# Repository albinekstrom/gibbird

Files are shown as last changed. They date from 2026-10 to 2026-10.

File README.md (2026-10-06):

# GibBird: balcony bird camera + e-ink frame

A camera on the balcony spots birds, works out the species, and an A4 colour
e-ink frame in the bedroom shows who visited today. It's based on teddymakesstuff's
"Avian Visitors" frame, but that one listens for birds (BirdNET audio, hence
"Heard Today") and this one watches with a camera.

It's set up for **Gothenburg** first: a curated list of 58 local species with Swedish
names and a Swedish poster. Everything that depends on location sits in one region
file, so you can make a list for anywhere else (see [Other locations](#other-locations)).

```
 BALCONY (outside the office window)            OFFICE (hidden behind the frame)
 ┌────────────────────────┐  2–3 m USB cable   ┌──────────────────────────────────┐
 │ IMX678 USB camera, 123°│ ─────────────────▶ │ Raspberry Pi 4                   │
 │ in a printed housing,  │                    │  gibbird cam:   motion → crop    │
 │ strapped to a railing  │                    │                 → classify       │
 │ post                   │                    │  gibbird frame: poster → driver  │
 └────────────────────────┘                    │  HAT → Waveshare 7.3" e-ink panel│
                                               └──────────────────────────────────┘
```

## Step-by-step

**Placement:** [docs/INSTALLATION.md](docs/INSTALLATION.md) describes where the frame,
camera, feeder and cables go (office window + balcony), plus the weatherproof camera
housing (`hardware/camera_housing.scad`).

1. **Buy the parts** (list below). Also get a feeder for the railing and place it
   about 1.2–1.5 m from the camera. The classifier needs the bird to fill a good part
   of the picture.
2. **Frame:** BGA "Ram Galant Glas" 13×18 cm. The 3D model's defaults match it. If you
   use another frame, measure its outer size, the recess (`rabbet`) and its depth.
3. **Print** `back`, `panel_tray`, `pod_cover` and `stand` from `hardware/frame_back.scad`,
   and `body`, `lid` and `bracket` from `hardware/camera_housing.scad`
   (see [3D print](#3d-printed-back)).
4. **Flash the SD card** with Raspberry Pi Imager → *Raspberry Pi OS Lite (64-bit)*.
   In the Imager settings, set Wi-Fi, enable SSH, and use the hostname `birdframe`.
5. **Build the frame.** Glass → passepartout → display panel → printed panel tray, in
   that order, into the frame. Feed the panel's flat cable through the tray's slot.
   Take the Pi 4 out of its aluminium case (keep the stick-on heatsinks), screw it onto
   the four bosses in the printed back, and plug the driver HAT onto it. Then connect
   the flat cable to the HAT and screw the back onto the frame. Power and camera cables
   leave through the spine at the bottom edge.
6. **Mount the camera** on a railing post next to the office window, with two hose
   clamps (see [docs/INSTALLATION.md](docs/INSTALLATION.md)). Run the cable along the
   window frame, in through the window seal, and up the spine.
7. **Install the software** ([Software](#software)). Use `gibbird classify` on a few
   photos and check the web page at `http://birdframe.local:8080`.
8. **Calibrate** at `http://birdframe.local:8080/calibrate` ([below](#zones-and-calibration)).
9. **Tune** `min_score`, the camera angle and the feeder position in the first week.

## Shopping list

This is the current build: a Pi 4 behind a Waveshare 7.3" e-ink panel, and an IMX678
USB camera outside the office window. Prices are from amazon.se, October 2026.

**Already owned:** Raspberry Pi 4 Model B with its fan and heatsinks, the official Pi 4
USB-C power supply, a microSD 32 GB High Endurance card, and the BGA "Ram Galant Glas"
13×18 cm frame (walnut).

**Main parts**

| Part | Notes | ≈ Price |
|---|---|---|
| **Waveshare 7.3" 6‑Color e‑Paper HAT (E)** (E Ink Spectra 6, 800×480) | Comes with the driver board and a 40-pin extension header. The driver board plugs straight onto the Pi, so no ribbon cable is needed | 1 258 kr |
| **Iyalezirk IMX678 USB camera module, 8 MP, 123°** | USB, 4K MJPEG, 38×38 mm board. Sony Starvis 2 sensor, good in grey winter light. Sold by a third-party seller | 864 kr + 33 kr |

**For the frame and the Pi**

| Part | Notes | ≈ Price |
|---|---|---|
| 90° USB-C adapter (male → female), **sideways-bent** type (plug comes out of the adapter's side) | The cable then turns down along the board towards the spine. Flip it 180° if it points up | 50–100 kr |
| USB-A → 2-pin fan cable, 5 V | Powers the Pi-Fan from a USB port, since the display board takes the GPIO pins | 30–60 kr |
| Screw kit M2.5 + M3 (stainless) | Pi 4× M2.5×6, pod cover 4× M3×10 countersunk, stand 2× M3×16 | 100–200 kr |
| 6× wood screws 2.5×10 mm countersunk | Back plate to the frame (pre-drill 1.5 mm) | 30–50 kr |
| Self-adhesive soft foam sheet (EVA), 3 mm | One layer in the panel tray's pocket supports the glass panel evenly (`foam_t` = 2.5 mm compressed) | 50–100 kr |
| PLA or PETG filament, ~300 g | For the indoor frame back and panel tray | – |
| Passepartout, white or black, 13×18 cm outer, window about **95×159 mm** | Hides the panel's border; window just inside the image area (160×96 mm). BGA's made-to-measure mat (179,90 kr), or cut black card yourself. Measure the panel first | 0–180 kr |

**For the camera outside**

| Part | Notes | ≈ Price |
|---|---|---|
| USB 2.0 extension, A‑male → A‑female, 2–3 m, **carries data** (flat if it crosses the window seal) | From the camera's cable to the Pi | 80–150 kr |
| 2× stainless hose clamps (band ≤ 12 mm) | Strap the camera bracket to a railing post without drilling. Choose a size that fits around the post plus the 8 mm base | 40–80 kr |
| EPDM/rubber tape | Between the bracket and the railing, to grip and protect the paint | 50 kr |
| Cable gland, IP68 (PG7 for a 3–6 mm cable, PG9 for 4–8 mm) | Seals the cable into the housing. Feed the camera end of the cable through it, since a USB-A plug won't fit. Set `gland_d` to the gland's thread | 50–80 kr |
| 2 mm plexiglas (acrylic) sheet, small piece | Score with a knife and snap a **32×32 mm** square for the housing's window (Bauhaus, Biltema, Jula) | 50–100 kr |
| 2 mm silicone O-ring cord or EPDM foam gasket tape | Seals the housing lid | 50–100 kr |
| Clear outdoor silicone | Glues the window disc in | 60–100 kr |
| Silica gel sachets | Keep the housing dry; replace each autumn | 40–80 kr |
| ASA filament (PETG works; never PLA outdoors) | For the camera housing and bracket | 250–350 kr |
| Feeder for the railing + sunflower seeds | 1.2–1.5 m from the camera. Check your housing association's rules first | 150–350 kr |
| Optional: conformal coating spray | Extra moisture protection for the camera board | 100 kr |

**Total for what's left to buy:** about **3 000–3 500 kr** including the display and camera.

## 3D-printed back

`hardware/frame_back.scad` is parametric. Install [OpenSCAD](https://openscad.org)
(the `openscad@snapshot` Homebrew cask works on macOS), open the file and use the
Customizer panel.

| Stand open | Stand closed |
|---|---|
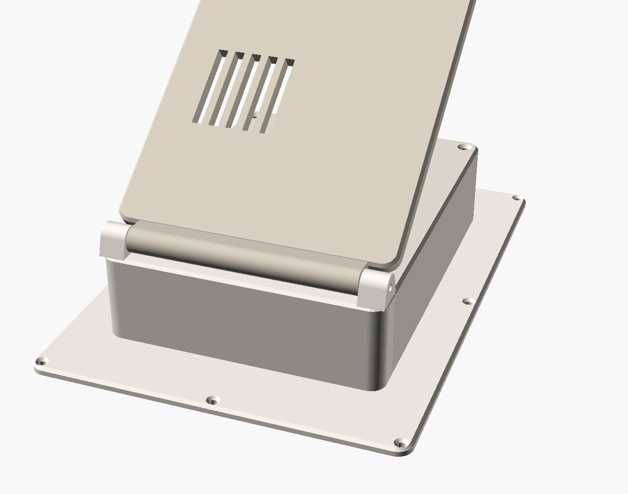
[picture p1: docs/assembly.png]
Back with the stand open
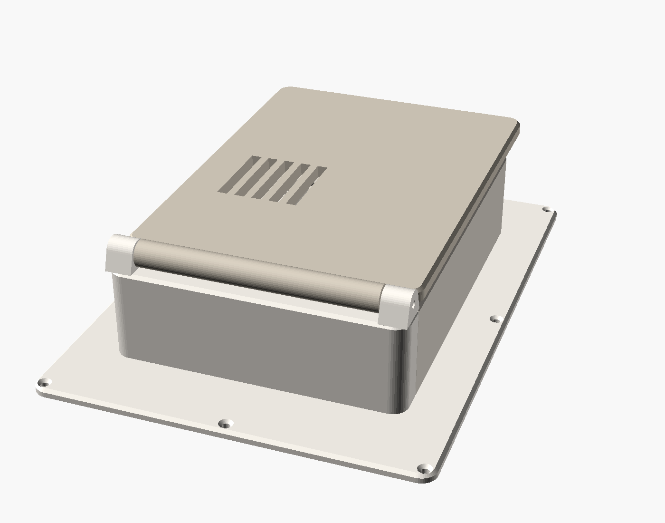
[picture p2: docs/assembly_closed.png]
Back with the stand closed
|  |  |

The back is one clean central column, and nothing else is visible:

- **Inside the frame:** glass → passepartout → **display panel** → **panel tray**. The
  tray is printed and holds the thin glass panel centred, supports its whole back
  (put a thin layer of foam in its pocket), and fills the rest of the 9 mm recess, so
  the back plate presses on it when screwed on.
- **Pod.** Hides the Pi (4 or 5) with the Waveshare driver HAT. The Pi screws onto four
  bosses on the plate. The pod **cover** is a separate part, printed roof-down for a
  smooth finish with no sagging spans. It comes off with 4 screws that are hidden
  under the stand, so you can reach the Pi without taking the back off the frame.
- **Fan.** A 30 mm fan mount and grille in the cover's roof, placed clear of the
  driver HAT. Air comes in through slots in the cover's bottom wall.
- **Spine.** A hollow channel from the pod down to the bottom edge, sloping down so the
  frame can lean back on its stand without the pod touching the table. The panel's
  flat cable comes up through a slot into the spine and runs inside it to the HAT. The
  power and camera cables leave through the spine at the bottom edge. Use a **90° USB‑C
  adapter**: there are 20 mm beside the Pi for the plug.
- **Stand.** A solid flap that closes over the pod and spine, so from behind the frame
  looks like a slab with one neat block on it. It has vent slots over the fan. It
  pivots on two M3×16 screws in towers at the top of the pod, and a stop tab sets the
  angle (`stand_open`, default 35°).
- **Plate.** 147×197 mm with rounded corners and softened edges, printed in one piece.
  It screws onto the frame with 6 small countersunk screws (2.5×10, pre-drill 1.5 mm).
  For a bigger frame, set `split_y` and print it in two glued halves.

**Assembly:** panel and tray into the frame (flat cable through the tray's slot) →
screw the Pi onto the bosses → plug the driver HAT onto the Pi (with its extension
header) → thread the power and camera cables up through the spine and plug them in
→ connect the panel's flat cable to the HAT → screw the back onto the frame → screw
the fan into the cover and plug its USB lead into the Pi → screw on the cover
(4× M3×10) → fit the stand (2× M3×16).

**Check when the display arrives:** the panel's outline (`panel`, default 111.2×170.2 mm),
its thickness, which edge the flat cable leaves from (`fpc_edge`, default bottom), and
the cable's width and length. If the cable is too short to reach the driver HAT, a
24-pin 0.5 mm FPC extension solves it. The file refuses to render if the cable slot
doesn't open into the spine or pod, if the slot is under the Pi, if the panel doesn't
fit the frame, or if the fan would sit over the HAT. The `stl/` folder has exports
made with the default numbers.

No part needs supports: plate and panel tray flat side down, cover roof down, stand
pod-side down. Use 0.2 mm layers, 3 walls and 15 % infill. PETG handles a warm windowsill
better than PLA. A matte or silk filament in one colour gives the cleanest look.

## Software

```
gibbird/           Python package
  camera.py        Picamera2 / OpenCV frame sources
  motion.py        background-subtraction motion detector + crop
  classifier.py    TFLite / LiteRT classifier (Google iNat birds, 964 species)
  watcher.py       motion → classify → confirm over several frames → visits
  store.py         SQLite visit log
  server.py        HTTP API + a simple phone page
  calibration.py   detection zones, image → real-world (cm) homography, size filter
  web/             calibration page
  render.py        e-ink poster (1200×1600) + language strings
  frame_app.py     polling, change detection, quiet hours
  data/regions/    species lists (gothenburg.csv)
hardware/          OpenSCAD model + STLs
scripts/           model download, region generator
systemd/           services (camera + frame, both on the same Pi)
```

How detection works. A low-resolution stream is checked for motion. Each moving region
is cut out of the full-resolution frame (12 MP on Camera Module 3) as a square, padded, and classified. A
species only counts when it wins 2 of 4 checks in a row, and it must be on the region
list. This stops the model from reporting, say, an American goldfinch in Gothenburg.
Sightings less than 2 minutes apart count as one visit. The most confident photo of
each visit is kept.

### Zones and calibration

Open `http://birdframe.local:8080/calibrate` while `gibbird cam` is running. It shows
a live snapshot.

- **Zones.** Outline where birds should be detected: railing, feeder, flower box.
  Motion outside the zones is ignored, so trees, the street and neighbours don't
  trigger anything.
- **Reference points.** Choose one flat surface where birds land, for example the
  face of the railing. Click 4 or more spots on it that you've measured with a tape,
  and type their positions in cm. From these the Pi works out how the picture maps to
  real centimetres. A white 50 cm grid is then drawn over the snapshot so you can
  check the fit. With 5 or more points it also shows a fit error.
- **What calibration gives you.** Zones are stored in centimetres. If the camera gets
  bumped, redo only the reference points and the zones stay where they were in the
  real world. Moving things outside the bird size range (default 6–80 cm) are ignored,
  such as a cat, a person or a flapping towel. Sizes are measured on the reference
  surface, so things far in front of or behind it are measured less accurately.

Everything is saved to `data/calibration.json` and applied immediately, without a
restart. The page has no login, so only use it on your home network.

The frame redraws only when the set of species or visit counts changes. It waits at
least 15 minutes between refreshes and stays dark 23:00–07:00. A full Spectra
refresh takes about 30 s and flashes. If nothing has been seen today, it shows the
last 7 days instead.

### Raspberry Pi (`birdframe`): deploy from your computer

You develop on your Mac and push to the Pi over SSH. The Pi doesn't need git or GitHub.

```bash
cp config.example.toml config.toml        # edit locally; it is copied on every deploy
scripts/deploy.sh --setup                  # first time: packages, SPI/I2C, venv, services
                                           # (reboots once; then run scripts/deploy.sh again)
scripts/deploy.sh                          # after every change: sync + restart
scripts/deploy.sh --logs                   # follow the logs
scripts/deploy.sh --status                 # services + CPU temperature
```

The target defaults to `albin@birdframe.local`; set `GIBBIRD_HOST=user@host` to change
it. The deploy uses rsync and leaves the Pi's `data/` folder (visits, photos,
calibration) and its Python environment alone. Python packages are only reinstalled
when `pyproject.toml` changes.

If the poster comes out upside down, set `rotation = 270`.

### On your Mac (no hardware)

```bash
python3 -m venv .venv && .venv/bin/pip install -e '.[dev]' ai-edge-litert
scripts/download_model.sh
.venv/bin/pytest
.venv/bin/gibbird -c config.example.toml classify photo.jpg      # test the model
.venv/bin/gibbird -c config.example.toml demo --photos ~/birds   # poster.png, dithered like the panel
.venv/bin/gibbird -c config.example.toml frame --once --preview p.png  # against a running cam
```

To run the full camera pipeline on a laptop, set `source = "opencv:0"` (webcam) or
`source = "clip.mp4"` (a video file).

## Other locations

```bash
# Uses GBIF bird records within 15 km. Local names in any ISO 639-2 language (swe, deu, fra, …)
python3 scripts/make_region.py --lat 59.33 --lon 18.07 --radius 15 --lang swe \
    --min-records 200 --out gibbird/data/regions/stockholm.csv
```

Then set `region = "stockholm"` in `config.toml`. The generated list includes ducks,
waders and seabirds that won't land on a balcony. Delete those rows by hand, as was
done for `gothenburg.csv`. You can also add `aliases` for look-alikes the model knows
under another name (e.g. *Corvus corone* → Hooded Crow).
For poster text in another language, add an entry to `TEXT` in `gibbird/render.py`.

## Ideas for later

- Raspberry Pi AI Camera or AI HAT+ for a real bird detector instead of motion.
- Add BirdNET (audio) as well, like the original, so it covers "heard" and "seen".
- A weekly poster on Sundays, and a "first of the year" highlight.

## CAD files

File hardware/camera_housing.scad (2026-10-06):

// GibBird — weatherproof housing v2 for a small USB board camera (default: the 38 x 38 mm
// IMX678 8MP 123° USB module), plus a tilting bracket that straps onto a balcony railing post.
//
// Use orientation: the camera looks along +Z, +Y is up. A smooth rounded shell with a
// rain hood over the window, sized from the lens's field of view so it never shows in
// the picture; the lid closes the back flush, with a gasket in
// a groove and a PG9 cable gland (big enough to pass a USB-A plug). All screws are
// inside the shell or under the lid. The board is held by four ribs and pressed into
// place by pegs on the lid, so it needs no screws.
//
// Built for Swedish weather (rain, snow, frost): print in ASA (best: UV- and cold-proof) or PETG,
// never PLA (brittle in frost, soft in sun). 4 walls, 30 % infill, no supports:
//   body:    back opening on the bed
//   lid:     outer face on the bed
//   bracket: base on the bed
//
// Mounting on the balcony railing (no drilling): two stainless hose clamps run through the
// tunnels in the bracket base and around a railing post; a groove in the back of the base
// centres it on the post. Put a strip of EPDM/rubber tape between bracket and post. The
// base also has two countersunk holes for screws or outdoor VHB tape on a flat surface.
//
// Hardware: 4x M3 x 12 + washers (lid), 2x M4 x 10 + washers (tilt, self-tapping),
// 2x stainless hose clamps (band <= 12 mm, size to fit post + base), PG9 cable gland,
// 2 mm acrylic window pane (32 x 32 mm square, cut from a sheet) + clear silicone, 2 mm silicone O-ring
// cord (or 2 mm foam gasket tape), a silica gel sachet.

part = "assembly"; // [assembly, body, lid, bracket]

/* [Camera board: MEASURE YOURS] */
board = [38, 38];
board_t = 1.6;
lens_len = 22;        // board front face -> front of the lens
lens_d = 12;          // diameter of the lens's front
fov_d = 123;          // diagonal field of view (IMX678 module: 123°)
aspect = [16, 9];
behind = 18;          // room behind the board for the connector and the gland

/* [Window] */
pane = "square";      // "square": a 2 mm acrylic piece you score and snap yourself (easy to make);
                      // "round": a bought round disc of disc_d
pane_size = 32;       // side of the square pane
disc_t = 2;           // pane thickness
hood_max = 20;        // rain/snow hood beyond the window; shortened automatically so the
                      // lens never sees it

/* [Shell] */
wall = 3.0;           // thick walls keep the camera's own heat in during winter
clear = 7;            // space around the board on each side (room for the screw bosses)
front_t = 3;
radius = 8;           // vertical edges
chamfer = 1.5;
boss = 7;             // lid screw bosses in the inside corners
screw_pilot = 2.6;    // M3 self-taps into the bosses
screw_clear = 3.4;
lid_t = 4;
groove_w = 1.8;       // gasket groove in the lid for 2 mm cord
groove_depth = 1.4;

/* [Cable] */
gland_d = 15.6;       // hole for the cable gland's thread: PG9 15.6, PG7 12.9, M12 12.4,
                      // M16 16.4. Feed the camera end of the cable through the gland.
weep_d = 2;

/* [Mount] */
pivot_boss_t = 5;     // round pads on the sides for the tilt screws
pivot_pilot = 3.4;    // M4 self-taps into the pads
pivot_clear = 4.4;
arm_t = 5;
arm_w = 16;
base = [76, 40, 8];   // thick enough for the hose-clamp tunnels
base_screw = 4.5;
post_w = 40;          // width of the railing post the bracket straps to (MEASURE)
strap = [13, 2.6];    // hose-clamp band tunnel (width, height)

/* [Hidden] */
$fn = 64;
eps = 0.01;
in_w = board.x + 2 * clear;
in_h = board.y + 2 * clear;
W = in_w + 2 * wall;
H = in_h + 2 * wall;
standoff = lens_len + 1;                   // lens stops 1 mm behind the window
// Field of view -> window size and the longest hood that stays out of the picture.
tan_d = tan(fov_d / 2);
tan_v = tan_d * aspect.y / norm(aspect);
win_d = ceil(lens_d + 2 * (front_t + 1) * tan_d + 1);
disc_d = win_d + 4;   // round pane diameter (when pane = "round")
hood_len = min(hood_max, floor((board.y / 2 + clear - win_d / 2) / tan_v) - 1);
D_in = standoff + board_t + behind;
D = D_in + front_t;
board_z = D_in - standoff - board_t;       // board's back face
corners = [for (sx = [-1, 1], sy = [-1, 1]) [sx, sy]];
boss_xy = [in_w / 2 - boss / 2, in_h / 2 - boss / 2];
pivot_z = D / 2;
arm_gap = W + 2 * pivot_boss_t + 1;
pivot_h = sqrt(pow(H / 2, 2) + pow(D / 2 + hood_len, 2)) + 3;   // room to tilt

echo(str("housing ", W, " x ", H, " x ", D + hood_len, " mm; window ", win_d, " mm, disc ", disc_d,
         " mm; hood ", hood_len, " mm; board back at z = ", board_z));
assert(disc_d / 2 < board.x / 2 - 2, "window disc too big to pass the board ribs: use a smaller lens_d/fov");
assert(pane != "square" || (pane_size / 2 < board.x / 2 - 2 && pane_size >= win_d + 3),
       "square pane must cover the window (win_d + 3) and pass the board ribs");

module rsquare(size, r) { offset(r = r) offset(delta = -r) square(size, center = true); }

module shell_solid(h) {
    hull() {
        linear_extrude(h - chamfer) rsquare([W, H], radius);
        translate([0, 0, h - chamfer]) linear_extrude(chamfer) rsquare([W - 2 * chamfer, H - 2 * chamfer], radius - chamfer);
    }
}

module body() {
    difference() {
        union() {
            shell_solid(D);
            // rain/snow hood: the roof continues past the window. Only the roof: with a
            // wide lens, side cheeks would show in the picture.
            translate([0, 0, D - eps]) difference() {
                intersection() {
                    linear_extrude(hood_len) rsquare([W, H], radius);
                    translate([-W, H / 2 - wall, 0]) cube([2 * W, wall, hood_len]);
                }
                // drip groove under the front edge, so water falls off instead of creeping back
                translate([-W, H / 2 - wall - 1, hood_len - 4]) cube([2 * W, 1.6, 1.6]);
            }
            // round pads for the tilt screws
            for (s = [-1, 1])
                translate([s * (W / 2 + pivot_boss_t / 2 - 1), 0, pivot_z])
                    rotate([0, 90, 0]) cylinder(d = arm_w, h = pivot_boss_t + 2, center = true);
        }
        // cavity
        translate([0, 0, -1]) linear_extrude(D_in + 1) rsquare([in_w, in_h], 2);
        // window, and the disc's seat on the inside of the front wall
        translate([0, 0, D_in - 1]) cylinder(d = win_d, h = front_t + 2);
        if (pane == "square")
            translate([-(pane_size + 0.4) / 2, -(pane_size + 0.4) / 2, D_in - eps]) cube([pane_size + 0.4, pane_size + 0.4, disc_t]);
        else
            translate([0, 0, D_in - eps]) cylinder(d = disc_d + 0.4, h = disc_t);
        // weep hole at the front of the bottom wall
        translate([0, -H / 2 - 1, D_in - 4]) rotate([-90, 0, 0]) cylinder(d = weep_d, h = wall + 2);
        // blind pilot holes in the pads (they stop short of the cavity)
        for (s = [-1, 1])
            translate([s * (W / 2 + pivot_boss_t + 1), 0, pivot_z])
                rotate([0, s > 0 ? -90 : 90, 0]) cylinder(d = pivot_pilot, h = pivot_boss_t + 2.5);
    }
    // inside: lid screw bosses in the corners...
    difference() {
        for (c = corners) translate([c.x * boss_xy.x, c.y * boss_xy.y, 0]) linear_extrude(D_in) square(boss, center = true);
        for (c = corners) translate([c.x * boss_xy.x, c.y * boss_xy.y, -1]) cylinder(d = screw_pilot, h = 13);
    }
    // ...and a rib on each wall that the board rests against (chamfered: prints without support)
    rib_reach = in_w / 2 - board.x / 2 + 2;
    for (a = [0, 90, 180, 270]) rotate([0, 0, a])
        hull() {
            translate([in_w / 2 - rib_reach, -4, board_z + board_t]) cube([rib_reach, 8, D_in - board_z - board_t]);
            translate([in_w / 2 - eps, -4, board_z + board_t - rib_reach]) cube([eps, 8, eps]);
        }
}
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

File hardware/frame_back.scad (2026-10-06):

// GibBird — back cover v2 for a picture frame holding a Waveshare 7.3" e-Paper (E) panel,
// with a Raspberry Pi 4/5 (+ the Waveshare driver HAT) hidden behind it.
//
// Coordinates are seen FROM THE BACK with the frame standing in portrait.
// Origin = bottom-left corner of the frame's back face, Z points away from the display.
//
// Design: one clean central column. A pod hides the Pi (its cover comes off with 4
// screws hidden under the stand), a hollow spine carries the power and camera cables
// out to the bottom edge, and a solid flip-out stand closes over both, so from behind
// the frame looks like a slab with a single neat block on it.
//
// Inside the frame, front to back: glass, passepartout (mat), display panel, and a printed
// tray that holds the thin glass panel centred and supports its whole back. The tray fills
// the rest of the frame's recess, so the back plate presses on it when screwed on.
//
// Parts and print orientation (all without supports):
//   back                    flat side down (frames up to ~250 mm fit in one piece;
//                           bigger ones: set split_y and print back_lower + back_upper)
//   panel_tray              flat side down
//   pod_cover               roof down (a textured plate gives a nice finish)
//   stand                   pod side down
//
// Workflow: measure your frame + display, edit the [Frame] and [Display header] values,
// pick a `part`, press F6 (render), then File > Export > STL.

part = "assembly"; // [assembly, back, back_lower, back_upper, panel_tray, pod_cover, stand]

/* [Frame: MEASURE YOURS] */
// Defaults: BGA "Ram Galant Glas" 13x18 cm (14.7 x 19.7 cm outside, 13 mm profile, 9 mm recess).
frame_w = 147;        // outer width of the frame (portrait)
frame_h = 197;        // outer height
rabbet_w = 131;       // recess on the back where the picture goes (13x18 cm + play)
rabbet_h = 181;
rabbet_depth = 9;     // "falsdjup"
glass_t = 2;
mat_t = 1.4;          // passepartout; 0 if you don't use one

/* [Display panel: Waveshare 7.3" e-Paper (E), portrait. CHECK when it arrives] */
panel = [111.2, 170.2];  // outline of the glass panel
panel_t = 1.2;
foam_t = 2.5;            // foam behind the panel, compressed (3 mm self-adhesive EVA sheet)
panel_shift = [0, 0];    // move the panel off-centre in the recess (mm)
fpc_edge = "bottom";     // edge where the flat cable leaves the panel: bottom|top|left|right
fpc_w = 26;              // width of the flat cable
fpc_pos = 0;             // cable position along that edge, from its centre (mm)

/* [Pod: hides the Raspberry Pi] */
pod_w = 110;
pod_y0 = 26;          // bottom edge of the pod, frame coordinates. High enough that the pod
                      // doesn't touch the table when the frame leans back on its stand.
cable_room = 20;      // inside the pod, right of and below the Pi, for cables
plug_room = 20;       // above the USB-A ports, for a right-angle plug
boss_h = 4;           // Pi stands this far above the plate (M2.5 x 6 screws)
boss_d = 6;
boss_hole_d = 2.2;
pi_tall = 24;         // tallest part above the Pi's board (driver HAT on its extension header)
hat = [65, 30];       // driver HAT footprint, lying along the Pi's GPIO edge
wall = 2.4;
roof_t = 2.4;
radius = 6;           // corner radius of plate, pod and stand
chamfer = 1.2;        // softened top edges
cover_screw = 3.4;    // 4x M3 x 10 countersunk, into bosses on the plate
cover_pilot = 2.6;

/* [Fan: 30 mm 5 V fan over the SoC, exhausting through the roof] */
fan = true;
fan_size = 30;
fan_t = 7;
fan_hole_spacing = 24;
fan_screw_d = 3.2;
fan_at = [45, 10];    // in Pi board coordinates; kept clear of the driver HAT, which covers
                      // the SoC side of the board, and blowing down past it

/* [Spine: hollow channel for the cables (and the panel's flat cable)] */
spine_w = 40;
spine_low = 12;       // height at the bottom edge; slopes up to the pod so the frame can lean back

/* [Back plate] */
plate_t = 3.2;
screw_d = 2.9;        // 6x wood screws 2.5 x 10 mm into the frame (pre-drill 1.5 mm)
screw_head_d = 5.2;

/* [Stand] */
stand_open = 35;      // how far the stand swings open (deg)
flap_t = 5;
hinge_r = 5;
hinge_gap = 0.6;
knuckle_w = 10;       // hinge towers at both ends
knuckle_clear = 0.5;
pin_d = 3.3;          // stand pivots on the smooth shank of an M3 x 16 screw...
pin_tap_d = 2.8;      // ...which self-taps into the hinge tower
pin_depth = 12;

/* [Split for printers smaller than the frame] */
split_y = 0;          // 0 = print the plate in one piece
lap = 16;

/* [Hidden] */
$fn = 48;
eps = 0.01;
pi_board = [56, 85];  // Pi lying vertically: GPIO edge left, USB-C right, USB-A at top
m_x = (frame_w - rabbet_w) / 2;
m_y = (frame_h - rabbet_h) / 2;
tray_t = rabbet_depth - glass_t - mat_t - 0.3;   // tray fills the recess behind the panel
panel0 = [m_x + (rabbet_w - panel.x) / 2, m_y + (rabbet_h - panel.y) / 2] + panel_shift;
panel1 = panel0 + panel;
// Slot for the panel's flat cable, just inside the edge it leaves from.
slot_l = fpc_w + 6;
slot_d = 8;
hdr = fpc_edge == "bottom" ? [(panel0.x + panel1.x) / 2 + fpc_pos, panel0.y + slot_d / 2 + 1]
    : fpc_edge == "top"    ? [(panel0.x + panel1.x) / 2 + fpc_pos, panel1.y - slot_d / 2 - 1]
    : fpc_edge == "left"   ? [panel0.x + slot_d / 2 + 1, (panel0.y + panel1.y) / 2 + fpc_pos]
    :                        [panel1.x - slot_d / 2 - 1, (panel0.y + panel1.y) / 2 + fpc_pos];
hdr_open = fpc_edge == "bottom" || fpc_edge == "top" ? [slot_l, slot_d] : [slot_d, slot_l];
pod_cx = frame_w / 2;
pod_x0 = pod_cx - pod_w / 2;
pod_x1 = pod_cx + pod_w / 2;
pod_in_x0 = pod_x0 + wall;
pod_in_x1 = pod_x1 - wall;
pod_in_y0 = pod_y0 + wall;
board0 = [pod_in_x1 - cable_room - pi_board.x, pod_in_y0 + cable_room];
pod_in_y1 = board0.y + pi_board.y + plug_room;
pod_y1 = pod_in_y1 + wall;
pod_in_h = boss_h + 1.6 + pi_tall + 3;        // above the plate top
top_z = plate_t + pod_in_h + roof_t;          // top of pod, spine and hinge base
axis_y = pod_y1 + hinge_r + 1.5;
axis_z = top_z + hinge_gap + hinge_r;
hinge_y1 = axis_y + hinge_r + 2;              // top edge of the hinge base
flap_len = axis_y - 3;
// Stop tab behind the hinge: it touches the hinge base exactly at `stand_open`.
tail = (hinge_r + hinge_gap - hinge_r * cos(stand_open)) / sin(stand_open);
function on_plate(p) = [board0.x + pi_board.x - p.y, board0.y + p.x];
pi_holes = [for (x = [3.5, 61.5], y = [3.5, 52.5]) on_plate([x, y])];
fan_c = on_plate(fan_at);
cover_bosses = [for (x = [pod_in_x0 + 3.5, pod_in_x1 - 3.5], y = [pod_in_y0 + 3.5, pod_in_y1 - 3.5]) [x, y]];
hdr0 = hdr - hdr_open / 2;
hdr1 = hdr + hdr_open / 2;

in_spine = hdr0.x >= pod_cx - spine_w / 2 + wall && hdr1.x <= pod_cx + spine_w / 2 - wall && hdr1.y <= pod_y0;
in_pod = hdr0.x >= pod_in_x0 && hdr1.x <= pod_in_x1 && hdr0.y >= pod_in_y0 && hdr1.y <= pod_in_y1;
assert(in_spine || in_pod, "the panel's cable slot must open into the spine or the pod: check fpc_edge/pod_y0");
assert(hdr1.x + 2 < board0.x || hdr0.x - 2 > board0.x + pi_board.x || hdr1.y + 2 < board0.y
       || hdr0.y - 2 > board0.y + pi_board.y, "the cable slot is under the Pi: raise cable_room");
assert(tray_t > panel_t + foam_t + 1.2, "the frame's recess is too shallow for glass + mat + panel + foam + tray");
assert(panel.x < rabbet_w && panel.y < rabbet_h, "the panel doesn't fit in the frame's recess");
// The fan must not sit over the driver HAT (HAT: GPIO edge = board y 56, inwards by hat.y).
assert(!fan || fan_at.y + fan_size / 2 < pi_board.x - hat.y, "fan is over the driver HAT: move fan_at");
for (b = cover_bosses)
    assert(b.x + 3.5 < hdr0.x || b.x - 3.5 > hdr1.x || b.y + 3.5 < hdr0.y || b.y - 3.5 > hdr1.y,
           "a cover screw boss is over the display header opening");
assert(split_y == 0 || split_y + lap / 2 < pod_y0, "the split seam runs through the pod: lower split_y");
assert(hinge_y1 < frame_h - 5, "the stand hinge is above the top of the frame");
assert(!fan || pod_in_h - boss_h - 1.6 - fan_t >= 8, "no room for the fan above the Pi's heatsinks");

echo(str("pod ", pod_w, " x ", pod_y1 - pod_y0, " mm, ", top_z, " mm deep; stand ", pod_w, " x ",
         flap_len, " mm; stop tab ", tail, " mm"));

// ---- helpers ---------------------------------------------------------------

module rbox2d(p0, p1, r) { translate(p0) offset(r = r) offset(delta = -r) square(p1 - p0); }

// Rectangle with selectively rounded corners: round = [bottom-left, bottom-right, top-right, top-left].
module rbox2d_sel(p0, p1, r, round) {
    pts = [[p0.x, p0.y], [p1.x, p0.y], [p1.x, p1.y], [p0.x, p1.y]];
    dirs = [[1, 1], [-1, 1], [-1, -1], [1, -1]];
    hull() for (i = [0 : 3])
        if (round[i]) translate(pts[i] + dirs[i] * r) circle(r = r);
        else translate(pts[i] + (dirs[i] - [1, 1]) * 0.005) square(0.01);
}
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

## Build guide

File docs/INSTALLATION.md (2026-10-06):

# Where everything goes

The frame stands in the office window, and the camera sits just outside that window,
looking at the balcony next to it. The camera cable comes in through the window
seal, so you don't drill anything and the cable run is short.

| Camera housing, front | Back (lid with gasket and cable gland) |
|---|---|
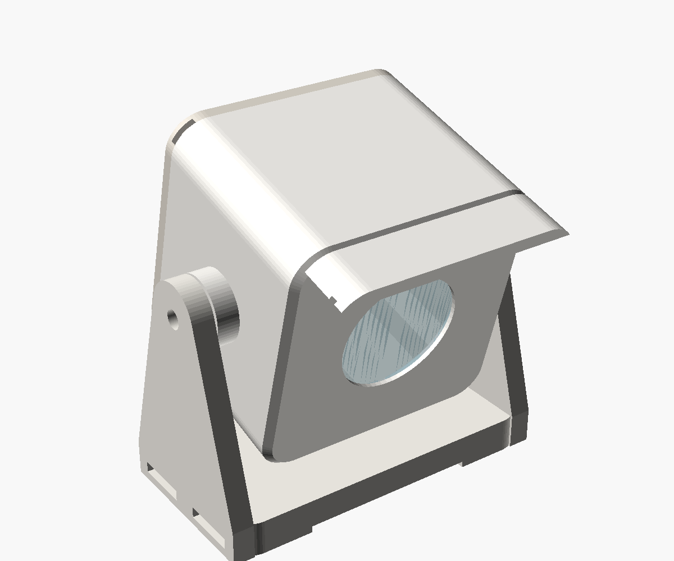
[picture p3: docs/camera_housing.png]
Camera housing, front
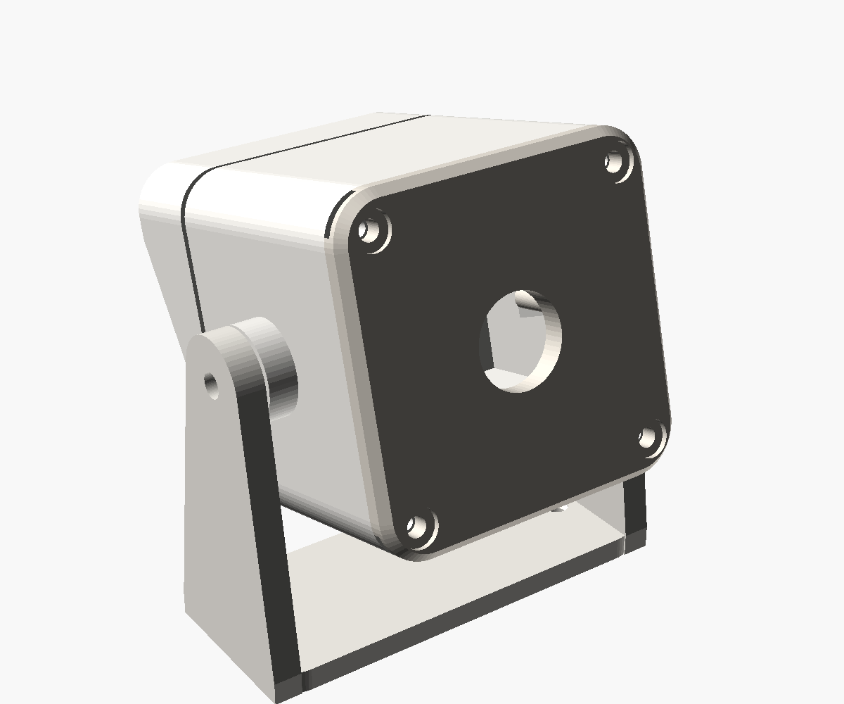
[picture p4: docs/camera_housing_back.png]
Camera housing, back
|  |  |

## Overview (seen from above)

```
                         ┌─────────────────────────── balcony railing ─────┐
                         │  ▲ flower boxes on the far railing              │
                         │                                                 │
                         │        BALCONY                                  │
                         │                                 ◆ FEEDER        │
                         │                                 (on the railing │
                         │                                  nearest the    │
                         │                                  window,        │
                         │                                  1–2 m from cam)│
   facade ───────────────┴──────────┐   ╲  view                           ─┘
                                     │    ╲
                           CAMERA ●──┘     (10–20° down, away from the sky)
       (outside, on the fixed window frame,
        upper left corner, under the slab above)
                                     ┊ cable: drip loop, then along the frame
   ══════════════ OFFICE WINDOW ═════╪══════════════════════════  (opens inwards)
                                     ┊ flat USB cable through the hinge-side seal
   ┌───────────── window seat / wooden shelf ─────────────────────┐
   │   [ FRAME ]  ← Pi 4 hidden in the back,      wall socket →  ◘ │
   │    stands on its flip-out stand                               │
   └───────────────────────────────────────────────────────────────┘
```

## 1. Camera: outside the window, upper left corner

**Where:** on the *fixed* outer window frame (the part that doesn't open), at the
upper left corner on the balcony side. Put it about 20–40 cm below the balcony slab
above, which keeps most of the rain off.

**Aim:** sideways along the facade, at the side of the balcony railing nearest the
window. Tilt it 10–20° down. That keeps the sky out of the picture (bright sky makes
the birds come out dark) and lets water run off the window disc. Your second photo is
roughly this view.

**Distance:** the feeder or perch should be **1–2 m** from the camera. With a wide 4K
camera, a 12 cm bird is about 190 px across at 1 m and 95 px at 2 m. The classifier
needs about 100 px to be reliable.

**Mounting on the balcony railing (recommended, no drilling):** strap the bracket to a
railing post with **two stainless hose clamps**. They run through the tunnels in the
bracket base, and a groove in the back of the base centres it on the post (set
`post_w` in the model to your post's width). Put a strip of rubber tape underneath so
it grips and doesn't scratch the paint. Tighten the clamps, set the tilt and pan by
eye using the live view at `/calibrate`, then tighten the two tilt screws.

**Other mounting options** (the base of the tilt bracket):
- **Without drilling:** outdoor double-sided tape (3M VHB, outdoor grade). Clean and
  dry the paint first, and apply it above 10 °C so it bonds. Let it set for 24 hours
  before you hang the camera on it. This is reversible, which is good if the
  housing association or landlord has rules about the facade.
- **With screws:** 2 stainless screws, 4×25 mm, into the wooden window frame. Ask the
  housing association (BRF) or landlord first.
- **Never on the opening sash.** It moves, and the camera would lose its aim.

## 2. Feeder

- **Where:** on the balcony railing on the side nearest the window, 1–2 m from the
  camera. A railing feeder or a seed tray in a flower box both work.
- **Background:** if possible, have the lawn and trees behind it, not the sky. Calm
  backgrounds make motion detection more reliable.
- **Seed tray:** use a feeder with a tray underneath to catch spilled seed. Spilled
  seed attracts rats and pigeons.
- **House rules:** many housing associations in Gothenburg ban feeding birds on
  balconies, so check your association's rules (ordningsregler) first. If feeding
  isn't allowed, a perch or a bird bath also attracts birds.

## 3. Camera cable: from the camera to the frame (about 2.5–3 m)

1. Make a **drip loop** under the housing: let the cable hang a few cm lower than the
   gland before it goes up again. Water then drips off the bottom of the loop instead
   of running into the housing.
2. Run the cable along the outer frame to the **hinge side** of the window. Hold it
   with outdoor cable clips or small pieces of VHB tape.
3. Go **through the window seal on the hinge side**, where the seal is squeezed least.
   Use a **flat** USB 2.0 extension cable here (1–2 mm thick). Close the window
   and check that it still latches and doesn't let in a draught.
4. Inside, run the cable along the window frame and down to the window seat, then
   up into the spine at the bottom edge of the frame's printed back.

**Length:** about 0.5 m outside, 0.3 m through the window and 1–1.5 m inside, so a
**3 m flat USB 2.0 extension** is enough. Together with the camera's own cable,
it stays under the 5 m limit for USB 2.0 without an amplifier.

If you're allowed to drill, a 10 mm hole through the fixed frame is neater. Drill it
sloping slightly downwards towards the outside, and seal it with silicone.

## 4. Frame and Pi: on the window seat

- **Where:** on the wooden window seat, on the right side, near a wall socket. The Pi
  sits hidden in the printed back of the frame. Power it from the official Pi 4 power
  supply, and use a mains extension cord if the socket is far away. Don't use a long
  USB-C cable, because the Pi then gets too little voltage.
- **Heat:** don't put it directly above a radiator or in the afternoon sun. The fan
  helps, but a Pi behind a frame in the sun can get hot. You can check the
  temperature with `scripts/deploy.sh --status`.
- **Wi-Fi:** the Pi connects over Wi-Fi. If the poster stops updating, check the signal
  in the office first.
- **E-ink** doesn't glow and has no glare, so it looks like a print. It can stand
  facing the room in daylight.

## 5. Weatherproofing for a Swedish winter

The camera has to cope with rain most of the year, plus wet snow, frost (often around
0 °C, sometimes −10 °C), wind, and condensation every time the temperature drops.

- [ ] **Choose a camera rated to −20 °C** (e.g. Arducam IMX708 USB, −20 to +70 °C).
      Boards rated "0–50 °C" often still work, but they're outside their rating on the
      coldest days.
- [ ] Print the housing in **ASA**: it handles UV and frost best. PETG is OK. Never use
      PLA, which gets brittle in the cold and soft in the sun.
- [ ] Cut the 32×32 mm window pane from 2 mm acrylic (score and snap). Glue it in from
      the inside with clear outdoor silicone, all the way round.
- [ ] Put 2 mm silicone O-ring cord (or foam gasket tape) in the lid groove. Screw the lid
      on evenly. **Close it on a dry day**, so you don't trap humid air inside.
- [ ] Put a **silica gel sachet** inside, and replace it each autumn. It stops the window
      from fogging up on cold mornings.
- [ ] Optional: brush the camera board with **conformal coating** (protective lacquer),
      keeping it off the lens and connectors.
- [ ] Feed the camera end of the cable through the gland from outside, then plug it in.
      Tighten the gland around the cable, not around the plug.
- [ ] Make sure the rain hood is on top and the small weep hole points down. The long hood
      keeps driving rain and snow off the window.
- [ ] Make the drip loop under the housing.
- [ ] Leave the camera powered all the time. It gives off about 1 W of heat, which keeps
      the inside a few degrees above the outside temperature and the window free of frost.
- [ ] Check after the first heavy rain, and again after the first snow, that it's dry
      inside.
- [ ] Check now and then that snow hasn't built up in front of the hood.

## 6. After mounting

1. `scripts/deploy.sh --logs`: check that the camera starts ("USB camera running at
   3840x2160").
2. Open `http://birdframe.local:8080/calibrate`:
   - Draw a **zone** around the feeder and the railing, so passing people and the
     trees in the background are ignored.
   - Add **reference points:** measure the railing with a tape (for example its corners
     and the feeder) and click those spots. The 50 cm grid should then line up with
     the railing.
3. Watch `http://birdframe.local:8080` for a few days and tune `min_score` if needed.

## Parts for this step

See the "For the camera outside" table in the [README](../README.md#shopping-list).
In short: the IMX678 USB camera, a 2–3 m USB 2.0 data cable, two stainless hose
clamps, a PG9 gland, a 32 mm window disc, a gasket, silicone, silica gel and ASA
filament.

The housing is `hardware/camera_housing.scad`. Measure your camera board (size, lens
length) when it arrives, then adjust the values at the top of the file and export
`body`, `lid` and `bracket`.

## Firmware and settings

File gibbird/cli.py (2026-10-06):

"""Command line entry point: `gibbird cam | frame | classify | demo`."""

from __future__ import annotations

import argparse
import logging
import random
import time
from datetime import datetime
from pathlib import Path

from . import config as config_mod
from .names import available_regions, load_labels, load_region, region_path

log = logging.getLogger("gibbird")


def cmd_cam(cfg: config_mod.Config, args) -> None:
    from .calibration import Calibration
    from .camera import open_source
    from .classifier import TFLiteClassifier
    from .server import make_server, serve_in_background
    from .store import Store
    from .watcher import BirdWatcher

    c = cfg.cam
    labels = load_labels(cfg.path(c.labels))
    region = load_region(region_path(c.region))
    data_dir = cfg.path(c.data_dir)
    data_dir.mkdir(parents=True, exist_ok=True)
    store = Store(data_dir / "visits.db")
    photos = data_dir / "photos"

    cal_path = cfg.path(c.calibration)
    calibration = Calibration.load(cal_path)
    log.info(
        "calibration: %s, %d zone(s)",
        f"{len(calibration.image_points)} reference points" if calibration.calibrated else "none",
        len(calibration.zones),
    )
    watcher = BirdWatcher(c, TFLiteClassifier(cfg.path(c.model), labels), region, store, photos, calibration)

    server = make_server(store, region, photos, c.http_host, c.http_port, watcher, cal_path)
    serve_in_background(server)
    log.info("API on http://%s:%d  (region: %s, %d species)", c.http_host, c.http_port, c.region, len(set(region.values())))
    for frame in open_source(c):
        watcher.process(frame)


def cmd_frame(cfg: config_mod.Config, args) -> None:
    from .display import PreviewDisplay, make_display
    from .frame_app import FrameApp

    f = cfg.frame
    display = PreviewDisplay(args.preview) if args.preview else make_display(f.display, f.rotation, f.saturation)
    app = FrameApp(f, display)
    if args.once:
        app.tick()
    else:
        app.run_forever()


def cmd_classify(cfg: config_mod.Config, args) -> None:
    import numpy as np
    from PIL import Image

    from .classifier import TFLiteClassifier

    c = cfg.cam
    region = load_region(region_path(c.region))
    clf = TFLiteClassifier(cfg.path(c.model), load_labels(cfg.path(c.labels)))
    for path in args.images:
        print(path)
        for p in clf.classify(np.asarray(Image.open(path).convert("RGB")), top_k=5):
            sp = region.get(p.sci.lower())
            local = f" = {sp.local or sp.en}" if sp else "  (not in region list)"
            print(f"  {p.score:5.2f}  {p.sci} ({p.common}){local}")


def cmd_demo(cfg: config_mod.Config, args) -> None:
    """Render a poster from made-up sightings, to tweak the design without hardware."""
    from PIL import Image, ImageDraw

    from .display import PreviewDisplay
    from .render import Tile, format_date, render_poster

    region = load_region(region_path(cfg.cam.region))
    species = sorted(set(region.values()), key=lambda s: s.sci)
    rng = random.Random(args.seed)
    photos = sorted(Path(args.photos).glob("*.jp*g")) if args.photos else []
    now = time.time()
    tiles = []
    for i, sp in enumerate(rng.sample(species, min(args.count, len(species)))):
        if photos:
            img = Image.open(photos[i % len(photos)])
        else:
            img = Image.new("RGB", (400, 400), tuple(rng.randrange(60, 200) for _ in range(3)))
            ImageDraw.Draw(img).ellipse([110, 110, 290, 290], fill=(240, 230, 210))
        name = sp.local if cfg.frame.names == "local" and sp.local else sp.en
        tiles.append(Tile(name, rng.randint(1, 9), now - rng.randint(0, 6 * 3600), img))
    tiles.sort(key=lambda t: -t.visits)
    f = cfg.frame
    img = render_poster(tiles, f.title, f.subtitle, format_date(datetime.now(), f.language),
                        max_tiles=f.max_tiles, lang=f.language, size=tuple(args.size or f.poster_size))
    PreviewDisplay(args.out, simulate=not args.no_simulate).show(img)
    print(f"wrote {args.out}")


def main(argv: list[str] | None = None) -> None:
    ap = argparse.ArgumentParser(prog="gibbird", description="Balcony bird camera + e-ink frame")
    ap.add_argument("-c", "--config", help="TOML config file (default: built-in defaults)")
    ap.add_argument("-v", "--verbose", action="store_true")
    sub = ap.add_subparsers(dest="cmd", required=True)

    sub.add_parser("cam", help="run the balcony camera + API (camera Pi)")

    p = sub.add_parser("frame", help="drive the e-ink frame (display Pi)")
    p.add_argument("--once", action="store_true", help="update once and exit")
    p.add_argument("--preview", metavar="PNG", help="write a PNG instead of using the panel")

    p = sub.add_parser("classify", help="classify still images (test the model)")
    p.add_argument("images", nargs="+")

    p = sub.add_parser("demo", help="render a poster with fake data")
    p.add_argument("--out", default="poster.png")
    p.add_argument("--count", type=int, default=6)
    p.add_argument("--photos", help="folder of bird photos to use in tiles")
    p.add_argument("--seed", type=int, default=1)
    p.add_argument("--no-simulate", action="store_true", help="skip the 6-colour dither preview")
    p.add_argument("--size", type=int, nargs=2, metavar=("W", "H"), help="poster size, e.g. 480 800")

    sub.add_parser("regions", help="list bundled region species lists")

    args = ap.parse_args(argv)
    logging.basicConfig(
        level=logging.DEBUG if args.verbose else logging.INFO,
        format="%(asctime)s %(levelname)s %(name)s: %(message)s",
    )
    cfg = config_mod.load(args.config)
    if args.cmd == "regions":
        print("\n".join(available_regions()))
        return
    {"cam": cmd_cam, "frame": cmd_frame, "classify": cmd_classify, "demo": cmd_demo}[args.cmd](cfg, args)


if __name__ == "__main__":
    main()

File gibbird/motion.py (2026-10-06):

"""Cheap motion detection on the low-resolution stream, used to trigger the classifier."""

from __future__ import annotations

import cv2
import numpy as np

# (x, y, w, h), normalised to 0..1 of the frame
Box = tuple[float, float, float, float]


class MotionDetector:
    def __init__(
        self,
        threshold: int = 25,
        min_area: float = 0.002,
        max_area: float = 0.5,
        learn_rate: float = 0.05,
        warmup_frames: int = 15,
    ):
        self.threshold = threshold
        self.min_area = min_area
        self.max_area = max_area
        self.learn_rate = learn_rate
        self.warmup_frames = warmup_frames
        self._bg: np.ndarray | None = None
        self._seen = 0

    def update(self, gray: np.ndarray, mask: np.ndarray | None = None) -> list[Box]:
        """Feed one grayscale frame; return moving regions, largest first.

        `mask` (uint8, same size, 255 = watch) limits detection to the detection zones.
        """
        g = cv2.GaussianBlur(gray, (5, 5), 0).astype(np.float32)
        if self._bg is None or self._bg.shape != g.shape:
            self._bg, self._seen = g, 1
            return []
        diff = cv2.absdiff(g, self._bg)
        cv2.accumulateWeighted(g, self._bg, self.learn_rate)
        self._seen += 1
        if self._seen <= self.warmup_frames:
            return []

        moving = (diff > self.threshold).astype(np.uint8) * 255
        if mask is not None:
            moving = cv2.bitwise_and(moving, mask)
        moving = cv2.dilate(moving, None, iterations=2)
        contours, _ = cv2.findContours(moving, cv2.RETR_EXTERNAL, cv2.CHAIN_APPROX_SIMPLE)
        h, w = gray.shape[:2]
        boxes = []
        for c in contours:
            area = cv2.contourArea(c) / (w * h)
            # Huge regions are lighting changes (clouds, sun), not birds.
            if self.min_area <= area <= self.max_area:
                x, y, bw, bh = cv2.boundingRect(c)
                boxes.append((x / w, y / h, bw / w, bh / h))
        boxes.sort(key=lambda b: b[2] * b[3], reverse=True)
        return boxes


def square_crop(img: np.ndarray, box: Box, scale: float = 1.6, min_px: int = 224) -> np.ndarray:
    """Square crop around a normalised box, padded by `scale` and kept inside the image."""
    H, W = img.shape[:2]
    x, y, w, h = box
    cx, cy = (x + w / 2) * W, (y + h / 2) * H
    side = int(min(max(max(w * W, h * H) * scale, min_px), W, H))
    x0 = int(round(min(max(cx - side / 2, 0), W - side)))
    y0 = int(round(min(max(cy - side / 2, 0), H - side)))
    return img[y0 : y0 + side, x0 : x0 + side]

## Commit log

2026-10-06 Balcony bird camera + e-ink frame: software, 3D-printed back, build guide
    [frame_back.scad]
2026-10-06 Track bundled region species list (fix over-broad ignore rule)
    [gothenburg.csv]
2026-10-06 Single Pi 5 behind the frame: bigger vented hood, USB camera cable
    - Back cover now holds a Pi 5 + Active Cooler on bosses, with an opening over
    the Inky header for a short ribbon cable and wall slots for power + camera
    - Stand lengthened to clear the taller hood; cables pass under the foot arch
    - USB webcams run at full HD (MJPG); webcam + localhost are the new defaults
    - README: one-Pi build steps, shopping list with camera cable options
    [frame_back.scad]
2026-10-06 Support the Pi 4 and a wide-angle Camera Module 3
    - Hood: slot for the flat camera ribbon (Pi 4 CSI connector), works for Pi 4 or 5
    - Default config: Camera Module 3 Wide at full 12 MP, smaller motion threshold
    - README: Pi 4 build notes (fan vs ribbon), wide-angle pixels-per-bird table,
    cable options by distance
    [frame_back.scad]
2026-10-06 Detection zones and real-world camera calibration
    - /calibrate page: draw zones on a live snapshot, click 4+ measured reference
    points to fit an image -> cm homography, with a 50 cm grid overlay
    - Zones stored in cm when calibrated, so they survive the camera being nudged
    - Motion outside zones is masked out; moving things outside 6-80 cm are ignored
2026-10-06 Deploy from the Mac to the Pi over SSH
    scripts/deploy.sh syncs code + local config with rsync, reinstalls Python deps
    only when pyproject.toml changes and restarts the services; --setup does the
    one-time Pi setup (apt packages, SPI/I2C + spi0-0cs overlay, venv, systemd).
2026-10-06 Default the 3D model to the BGA Galant A4 frame
    [frame_back.scad]
2026-10-06 Fan mount, zip-tie cable management, 4K USB camera for long runs
    - Hood roof: 30 mm fan mount + grille over the SoC (fan powered from USB)
    - Zip-tie anchors below the cable slots (strain relief) and along the cable path
    - CSI slot off by default; USB camera on a 5 m USB 2.0 cable is the default,
    OpenCV keeps only the newest frame so 4K MJPEG decoding doesn't lag
    [frame_back.scad]
2026-10-06 README: update total for 7.3" + USB camera
2026-10-06 Weatherproof camera housing + placement guide
    - hardware/camera_housing.scad: sealed box for a USB board camera (window disc,
    visor, O-ring groove, PG9 gland in the lid, weep hole, screwless board mount)
    on a tilting bracket
    - docs/INSTALLATION.md: camera outside the office window, feeder on the nearest
    railing, cable through the window seal, frame on the window seat
    [camera_housing.scad]
2026-10-06 Redesign: clean central column back + smooth camera housing
    Frame back v2: centred pod with a separate roof-down cover (4 screws hidden
    under the stand), hollow spine hiding all cables, solid flip-out stand with fan
    vents and an integrated hinge, rounded/chamfered edges, seam as a design line.
    Camera housing v2: screws inside the shell, built-in rain hood, flush lid with
    gasket groove, support-free printing, slimmer bracket. New renders in docs/.
    [camera_housing.scad, frame_back.scad]
2026-10-06 Camera housing and guide for Swedish winter: ASA, longer hood, thicker walls
    [camera_housing.scad]
2026-10-06 Support Waveshare 7.3" (E) display and the IMX678 camera; railing mount
    - display = "waveshare:epd7in3e" uses Waveshare's bundled MIT driver; setup
    removes the Inky-only spi0-0cs overlay (Waveshare needs hardware CS0)
    - Camera housing sizes its window and rain hood from the lens's field of view
    (123° IMX678: 28 mm window, 12 mm roof-only hood with drip groove)
    - Bracket straps to a railing post with two hose clamps, centred by a groove
    - Shopping list updated for the chosen parts
    [camera_housing.scad]
2026-10-06 Frame back for the BGA Galant 13x18 frame and the Waveshare 7.3" panel
    - Printed panel tray holds the thin glass panel centred and fills the 9 mm recess
    - Panel's flat cable comes up through a slot into the spine, which now slopes down
    so the frame can lean back on its stand; pod raised clear of the table
    - Pod deeper for the driver HAT, fan moved clear of it; plate prints in one piece
    - README: build steps, assembly order and shopping list for this setup
    [frame_back.scad]
2026-10-06 Square cut-it-yourself window pane, foam-thickness tray pocket, clearer parts notes
    [camera_housing.scad, frame_back.scad]
